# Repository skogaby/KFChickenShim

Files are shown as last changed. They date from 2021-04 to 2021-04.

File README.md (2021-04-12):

# KFChickenShim - Make your Sound Voltex 4 cabinet feel new again

So, you bought a Sound Voltex 4 cabinet, but weren't able to secure an official or clone upgrade kit for Sound Voltex V?

This is **KFChickenShim**, a simple PCB that adapts the various JST connectors found on a Sound Voltex IV IO board (known as **KFCA**) to standard connectors that allow you to easily connect the board to an off-the-shelf PC. Doing this, you can utilize a solution known as **KFChicken**, combined with **SpiceTools**, to run SDVX 5 or newer inside an older cabinet, complete with full IO, card reader, working lights, headphone support, etc. In addition, there is no perceivable latency or negative affect on gameplay, though your in-game offsets may not be what you're typically used to and might need adjustment for the new setup.

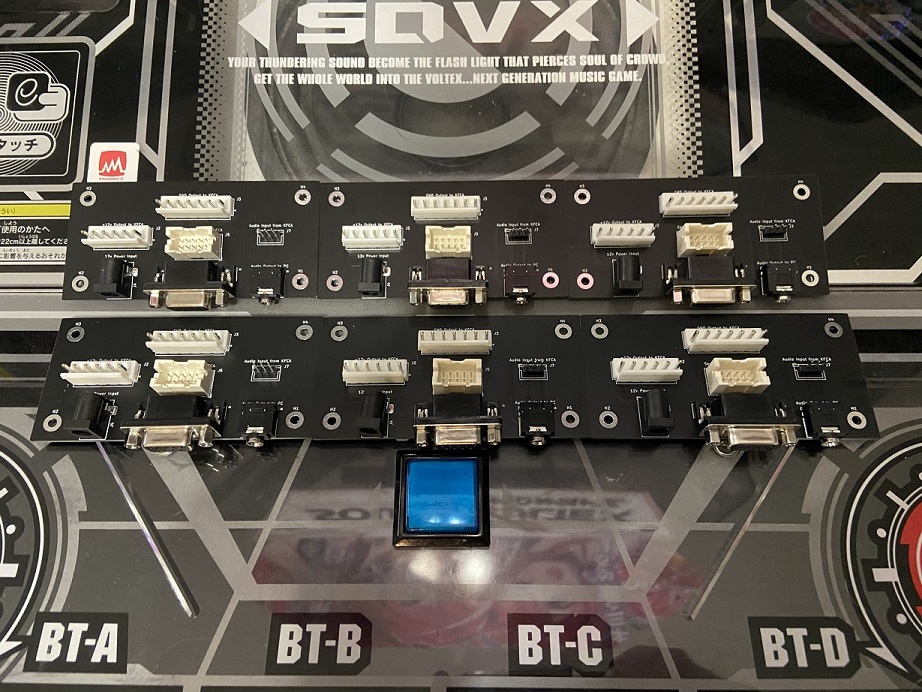
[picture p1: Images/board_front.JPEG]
PCB image 1

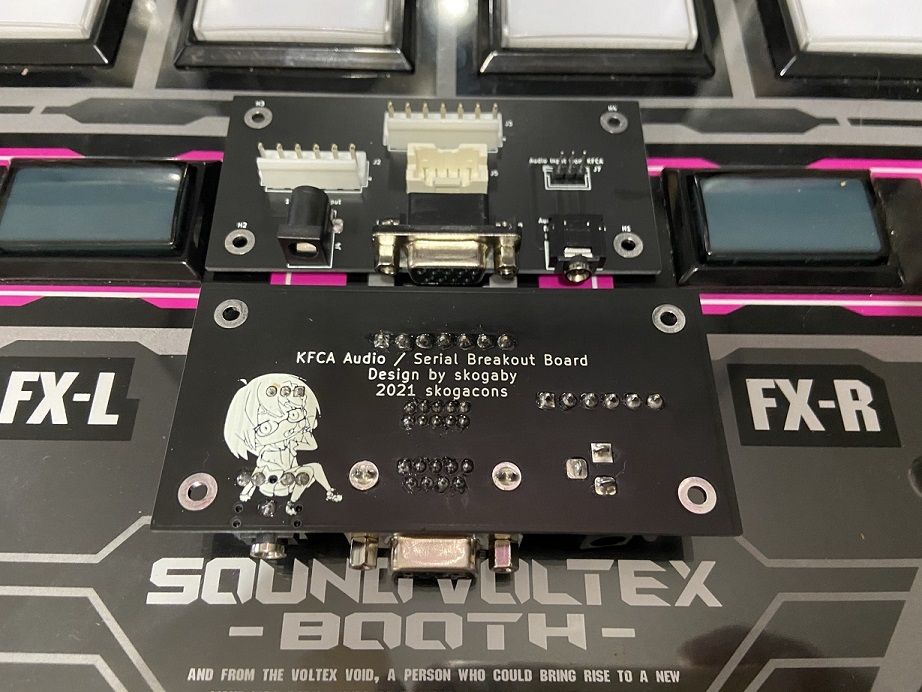
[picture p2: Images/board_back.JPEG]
PCB image 1


## Requirements

If you buy a pre-made PCB from me, you'll need the following:

* A KFChickenShim PCB (plus the components below)
  * DB9 serial cable. (**NOTE:** I've had better luck using DB9 serial -> USB cables, instead of using my motherboard's onboard serial port)
  * 3.5mm audio cable
  * 12v DC power adapter (5.5mm barrel jack connector)
* A newer PC that's powerful enough to run SDVX 5
* SpiceTools + KFChicken

Additionally, if you're ordering and assembling your own PCB, you'll need the following connectors:
* JST VH (6-pin and 7-pin)
* JST XAD (2x5-pin)
* 3x 2.5mm or 2.54mm pins (for the audio, I couldn't identify the exact JST connector Konami used for this but bare pins work fine)
* 5.5mm DC power barrel jack
* Sparkfun DB9 serial port (others might fit but the footprint was for this one, specifically)
  * https://www.sparkfun.com/products/429
* Sparkfun 3.5mm audio port (others might fit but the footprint was for this one, specifically)
  * https://www.sparkfun.com/products/8032

## Setup

Here are the instructions for setting up the board for use. I will not cover PCB assembly, all of the components are pretty self-explanatory in terms of placement on the board (they all have exactly one spot).

### Hardware Setup

#### Step 1: PC Removal

The first thing you'll want to do is remove the original BemaniPC from the cabinet. You'll need to disconnect every cable and remove the PC **entirely**, as the KFCA board is inside the PC case. In the below image, the board in the red rectangle is the one we're after.

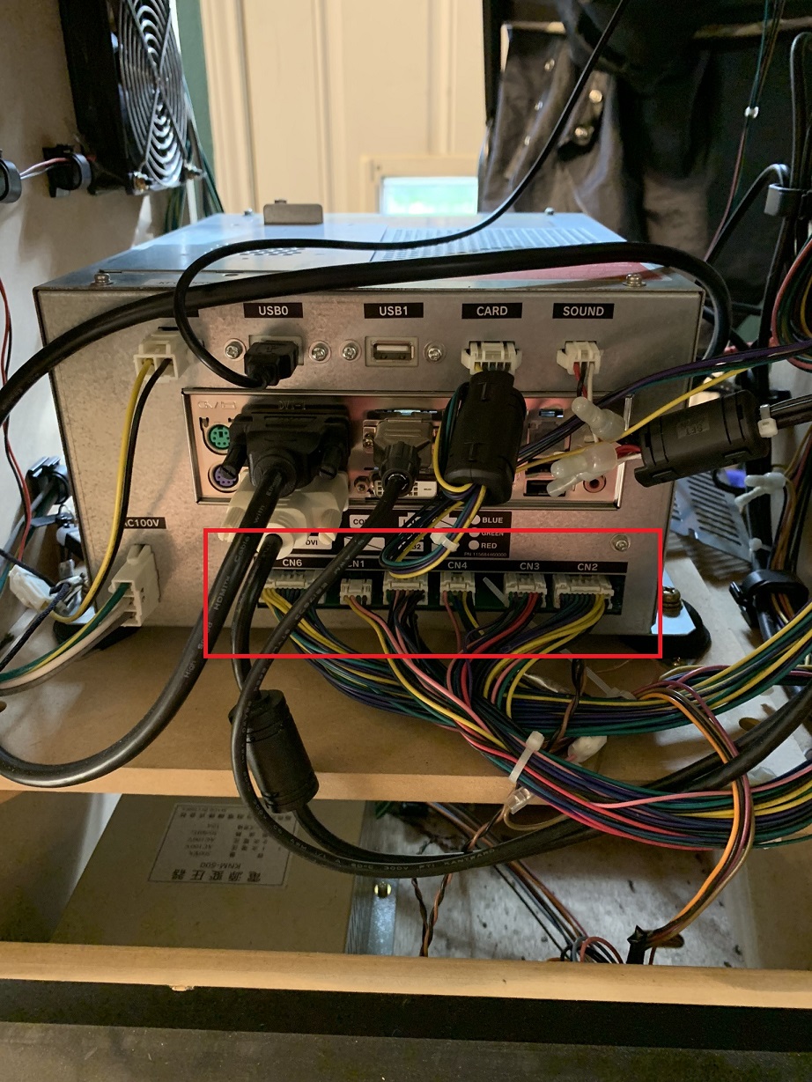
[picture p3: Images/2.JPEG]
BemaniPC


#### Step 2: Removing the KFCA board

Once the PC is removed from the cabinet, you'll need to remove the KFCA board from inside the PC case, which means you'll need to unscrew the case of the BemaniPC so you can get inside it. **NOTE**: If your cab is a gen 1 cabinet, your PC may look different from mine, but the process should be similar in terms of removing the IO.

Once the top is removed, you should see the exposed motherboard of the original PC. You'll more or less want to unplug all cables from the motherboard, to make it easy to remove since the KFCA sits underneath the motherboard. In the picture below, the connector in the red rectangle is the serial coming from the KFCA, and will be plugged into the KFChickenShim board.

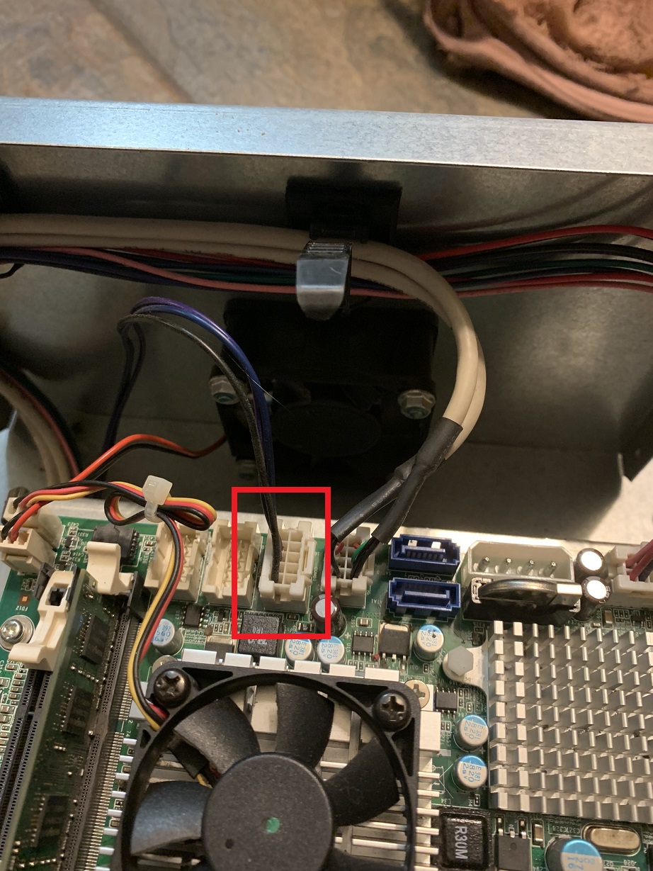
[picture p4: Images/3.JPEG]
Serial plug


Once the motherboard is removed entirely, you'll be greeted with a view similar to below.

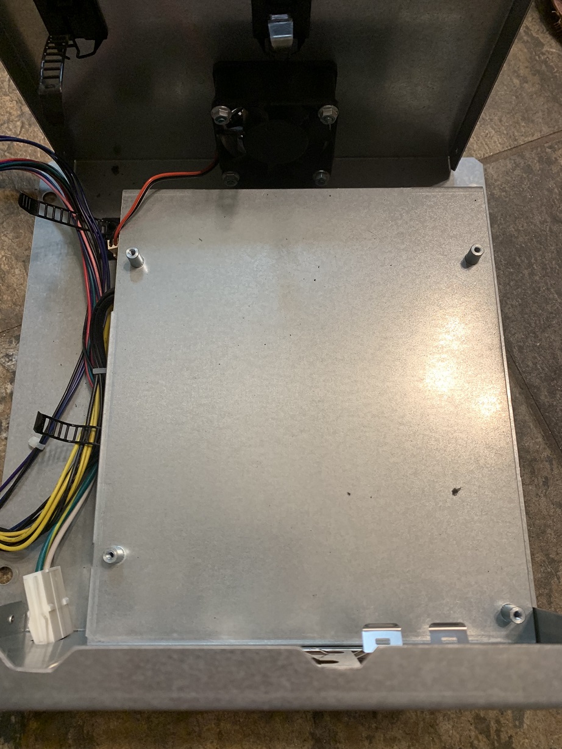
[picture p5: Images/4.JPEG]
Mobo mount


Go ahead and remove the metal plate that the motherboard was mounted to. Below it, you should see the KFCA board itself, as well as the power supply unit for the PC and the KFCA board.

***KFCA Board***

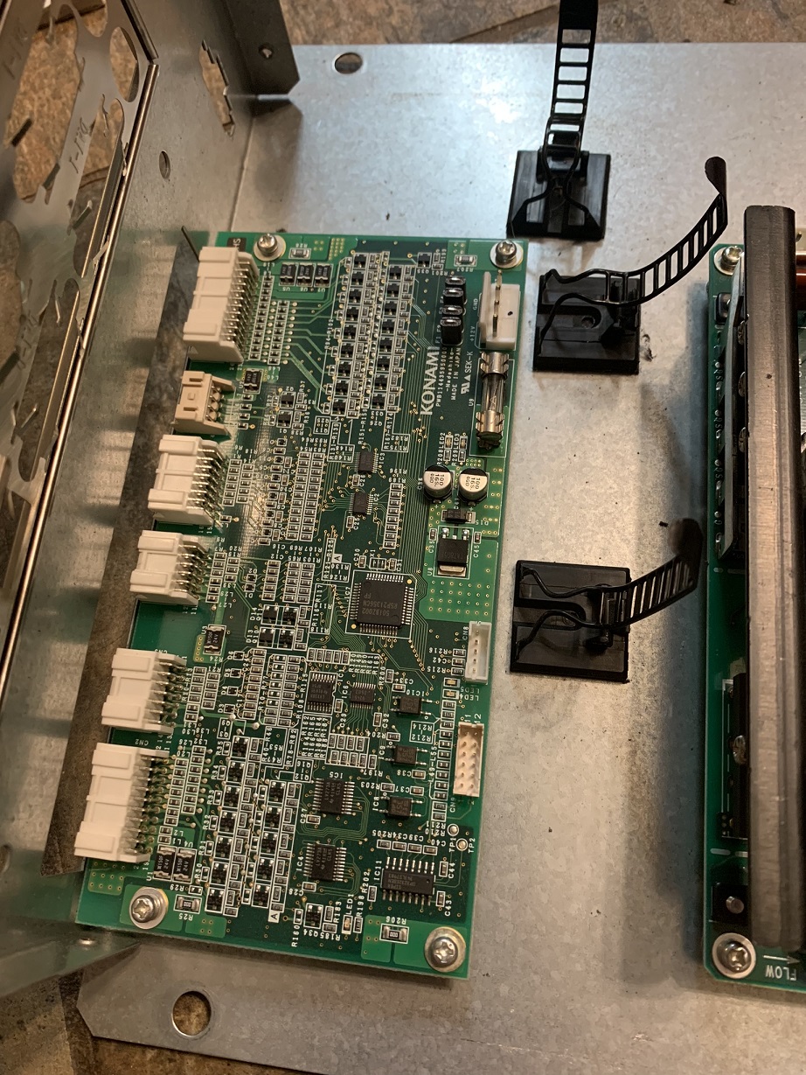
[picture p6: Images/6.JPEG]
KFCA Board


***Power supply, with power connectors for the KFCA board***

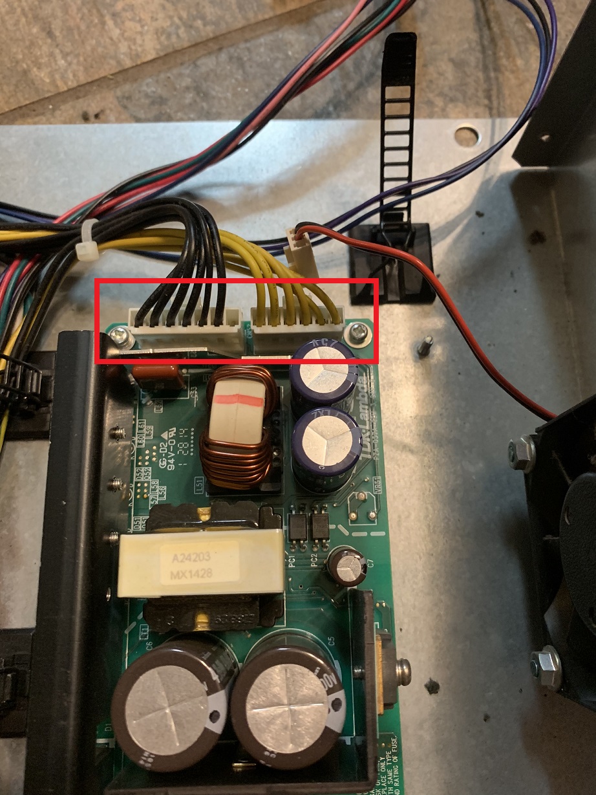
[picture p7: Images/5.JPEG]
BPC PSU


Once you unscrew the KFCA board, it should be free and ready for use.

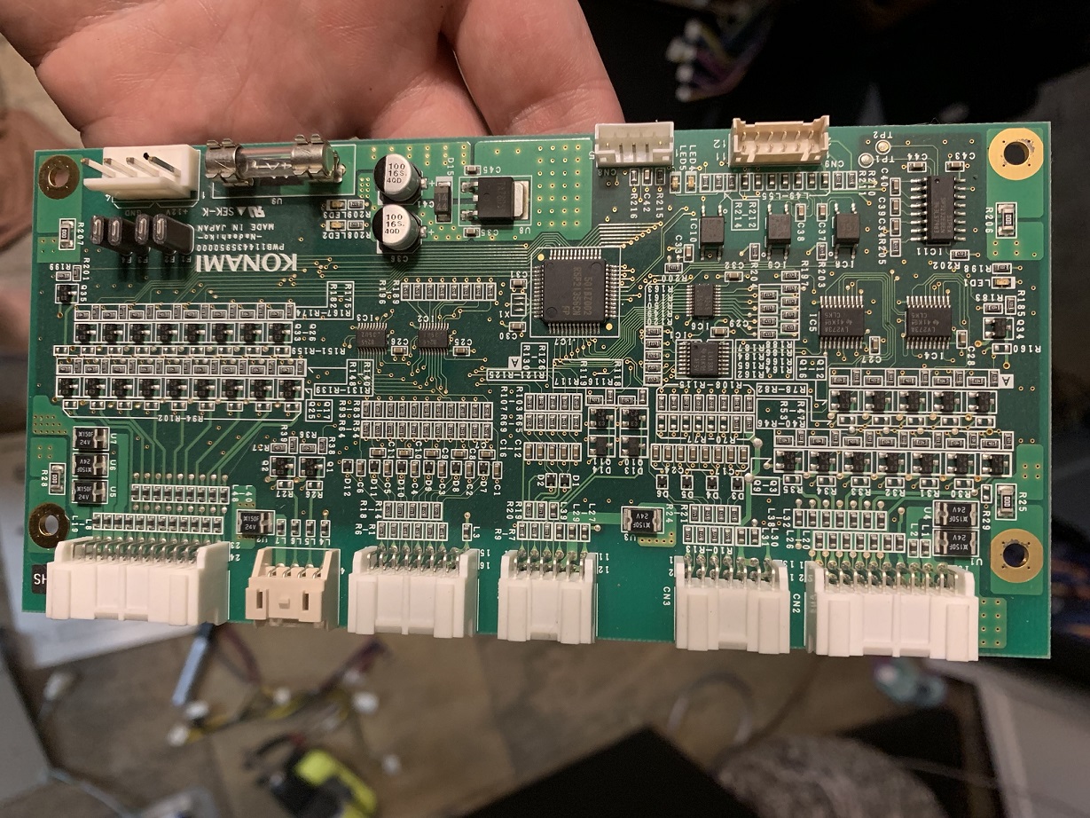
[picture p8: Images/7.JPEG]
Fresh KFCA


Below is the wiring harness that you should now have onhand for the KFCA board. Yours probably also has a plug that previously powered the PC, I just cut that off of mine since it's no longer being used. The wiring harness in the image is labeled appropriately, as we'll be referring to these later during assembly.

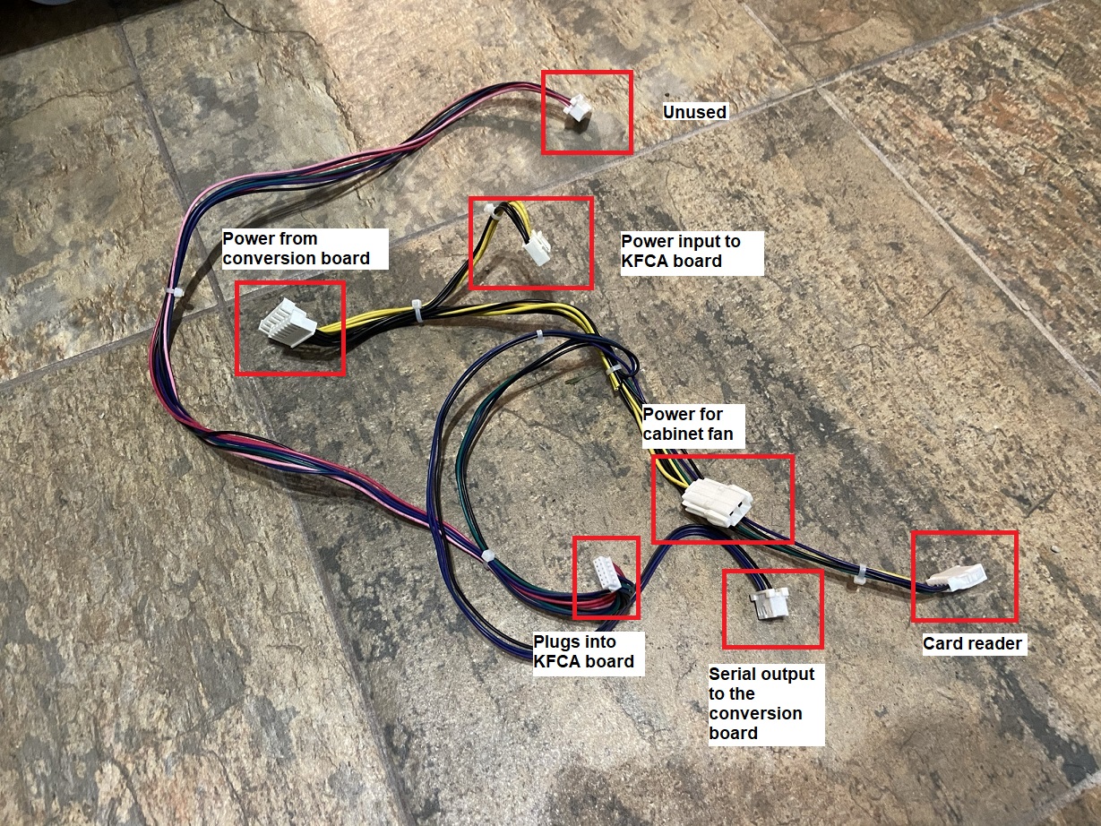
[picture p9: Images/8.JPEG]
Wiring Harness


#### Step 3: Installing the KFCA to the new PC

**NOTE:** I am *NOT* going to cover how to install the PC itself into your cabinet. This step can vary wildly depending on your setup. However, here is a picture of my personal cabinet, with a new PC installed and the IO removed. Please note that most cabinets have a 120v passthrough outlet sort of dangling at the end of a cord inside the cabinet. I highly recommend using this to power everything, but I had to pull that cable out of my cab for a different machine that needed one, so I spliced a regular wall outlet into the cab's power supply's 120v out. If you go this route, install an outlet cover box over the outlet (not pictured here).

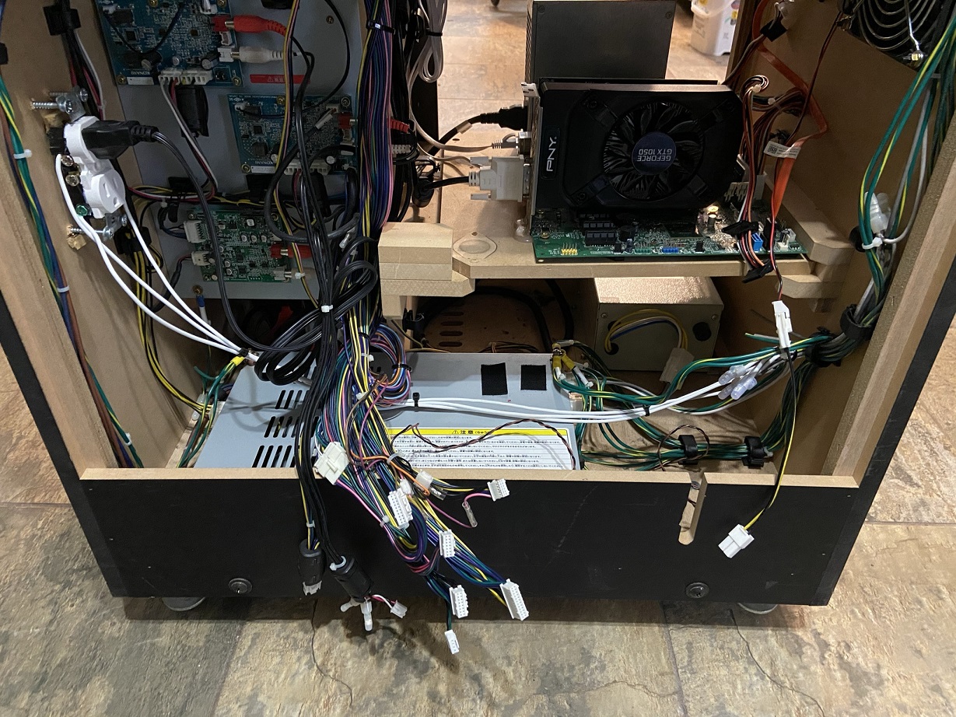
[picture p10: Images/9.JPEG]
Empty cab and PC


I'd also recommend making some sort of board like below with actual PCB/motherboard standoffs screwed into the wood. This will let you mount the PCBs inside the cab cleanly.

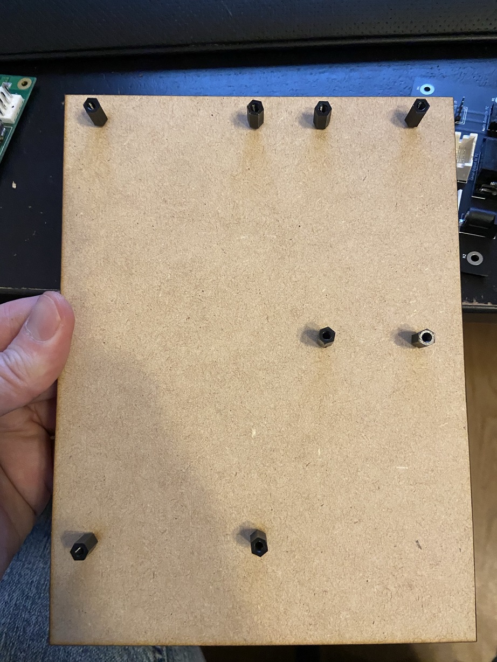
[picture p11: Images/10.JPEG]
Mounting panel

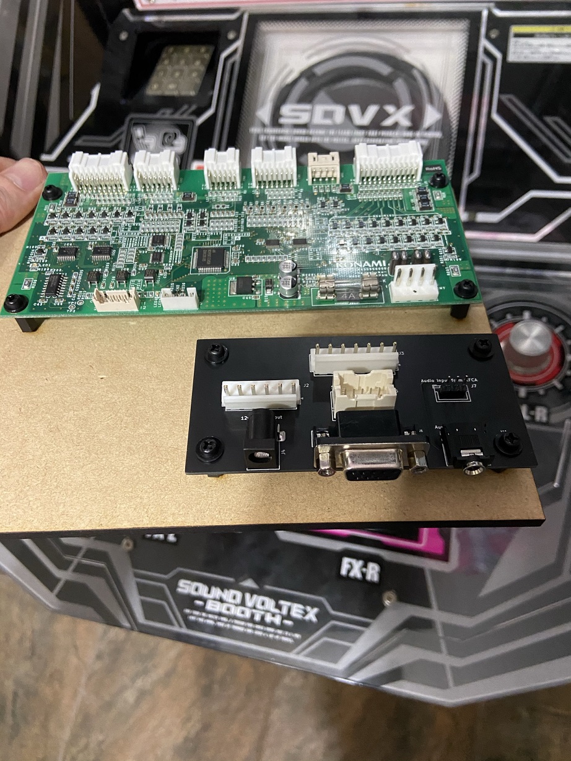
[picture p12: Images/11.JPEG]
Mounted PCBs


Go ahead and hook up the cables to the KFCA that are dangling inside the cabinet that previously connected to the front of the BemaniPC.

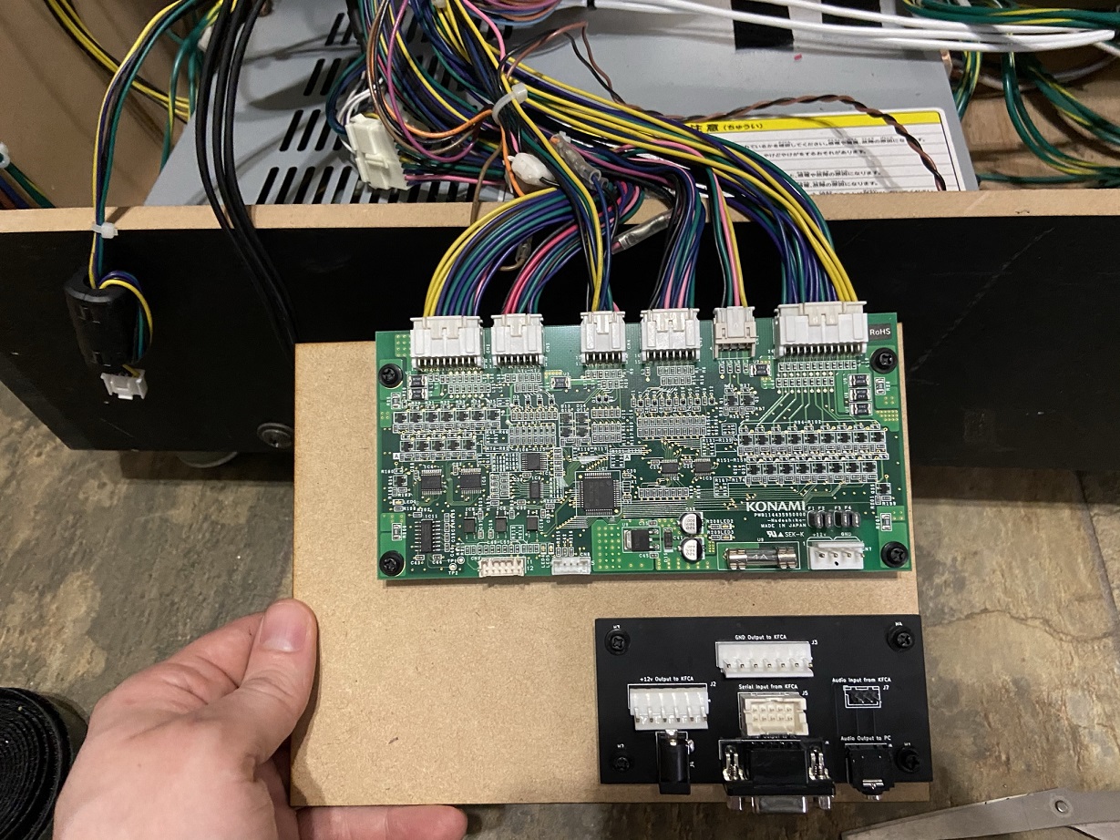
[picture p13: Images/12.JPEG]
First connections


Next, connect the power connections from the KFChickenShim board to the KFCA via the wiring harness pulled from the original cabinet. Yellow is 12v, black is ground.

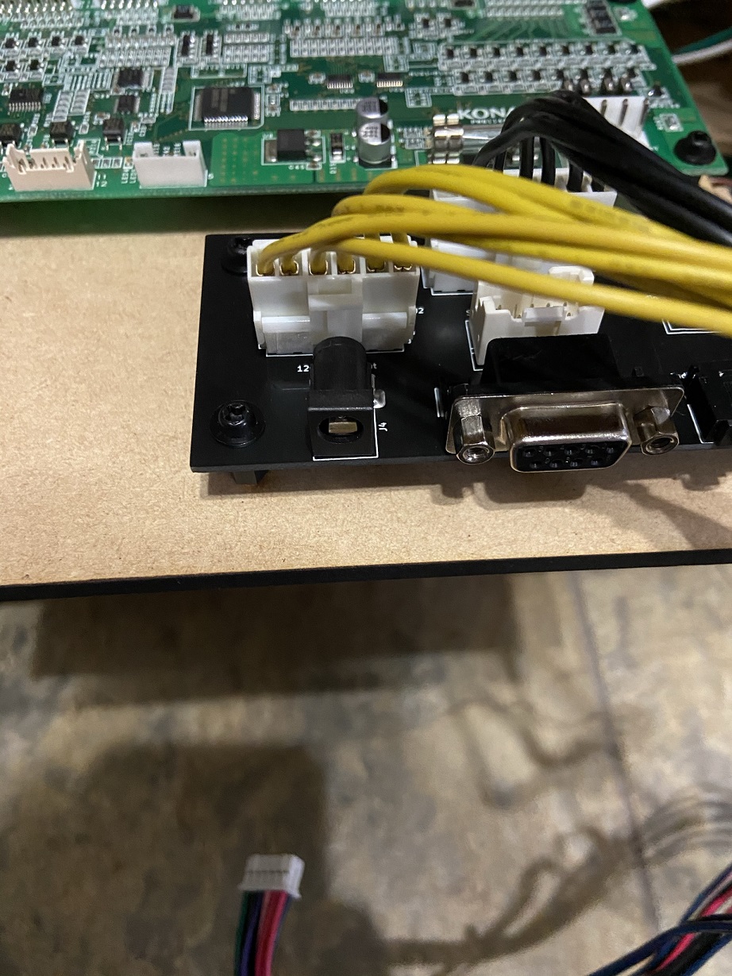
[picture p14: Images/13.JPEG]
Power

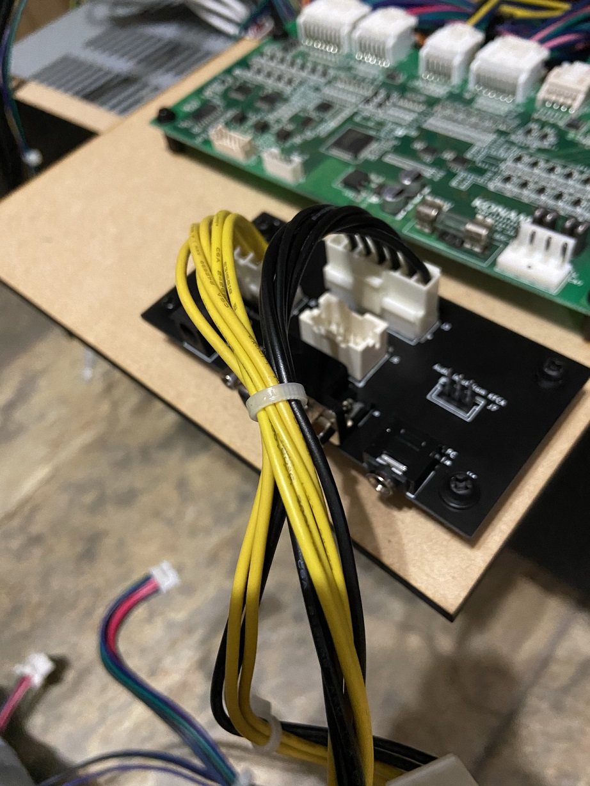
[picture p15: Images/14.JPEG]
Ground


Now connect the power cable to the KFCA board itself from the wiring harness.

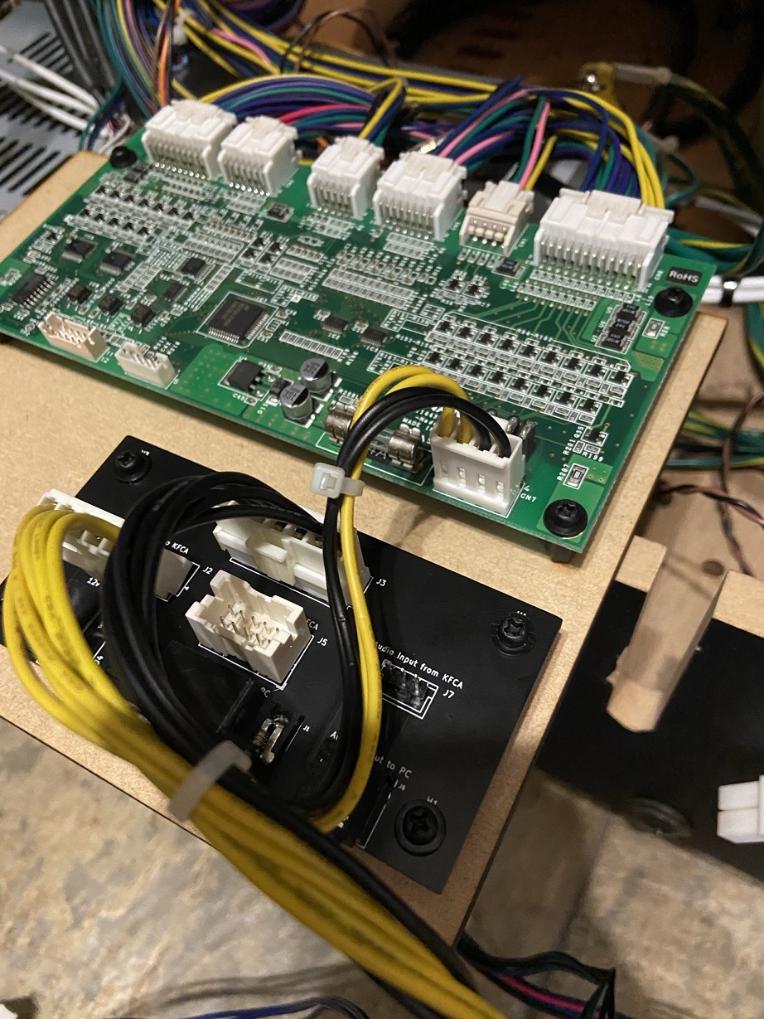
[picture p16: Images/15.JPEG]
KFCA power


Next, connect the wiring harness power for the cabinet fan that sits next to the PC.

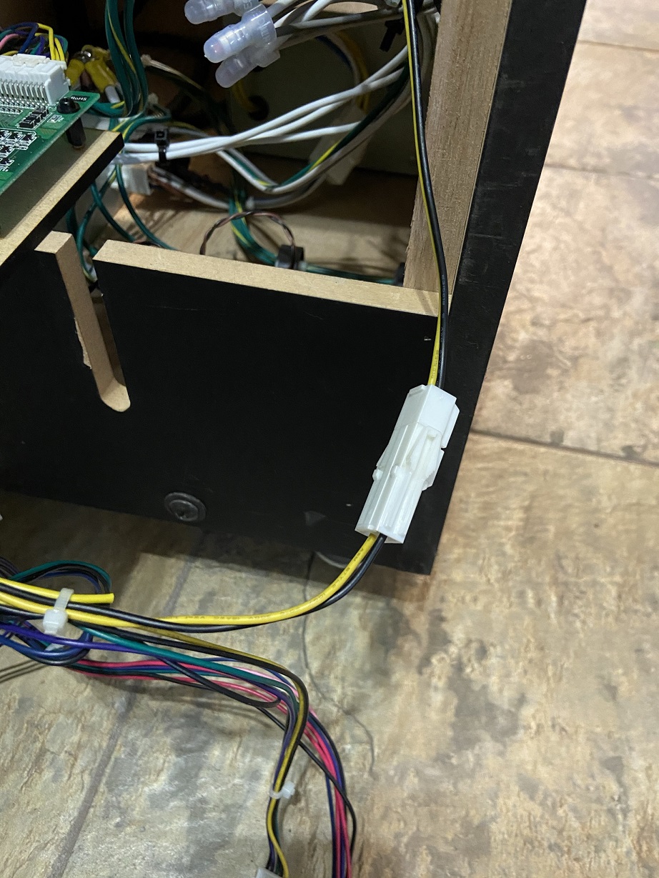
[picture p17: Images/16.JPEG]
Fan power


Connect the audio connector that's inside the cabinet (should be connected to 3 sets of red/white RCA cables on the other end) to the KFChickenShim board. Note the orientation of the plug, if it's plugged in backwards your left and right audio will be swapped.

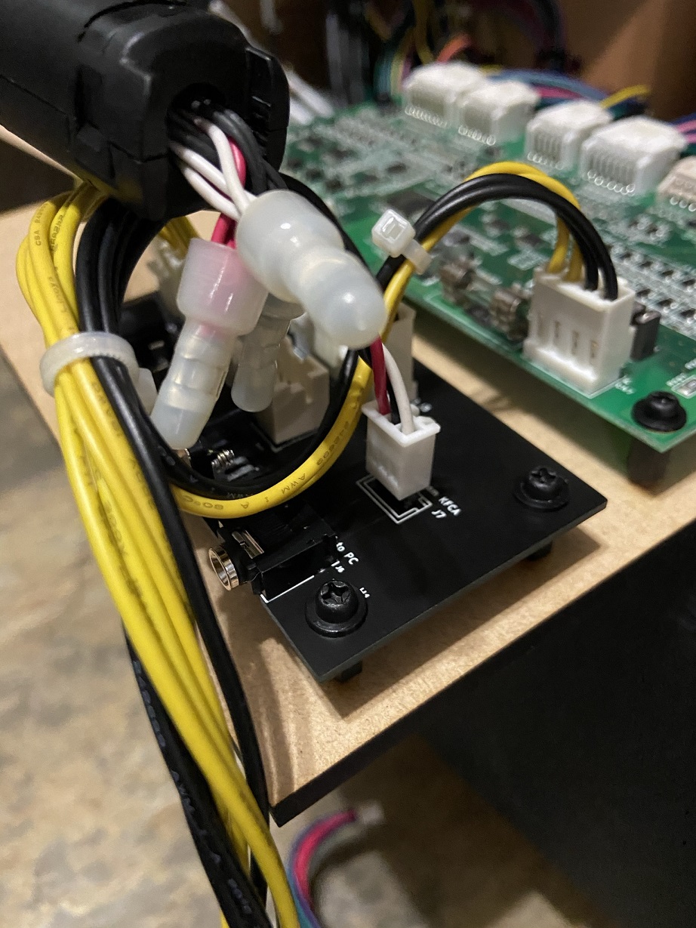
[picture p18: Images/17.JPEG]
Audio


Connect the card reader to the wiring harness from the KFCA.

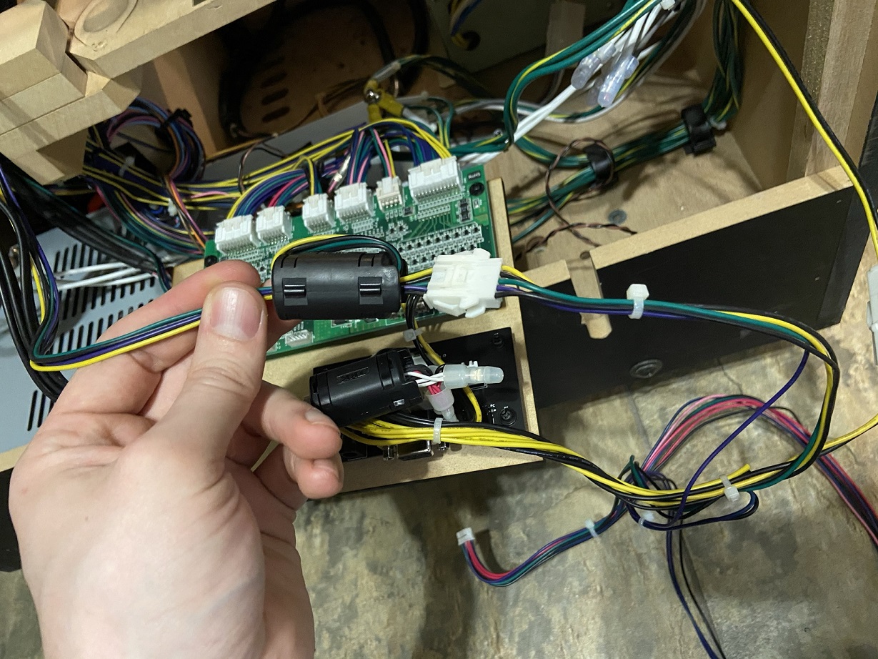
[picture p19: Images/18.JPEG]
Card reader


Connect the serial from the wiring harness to the KFChickenShim board.

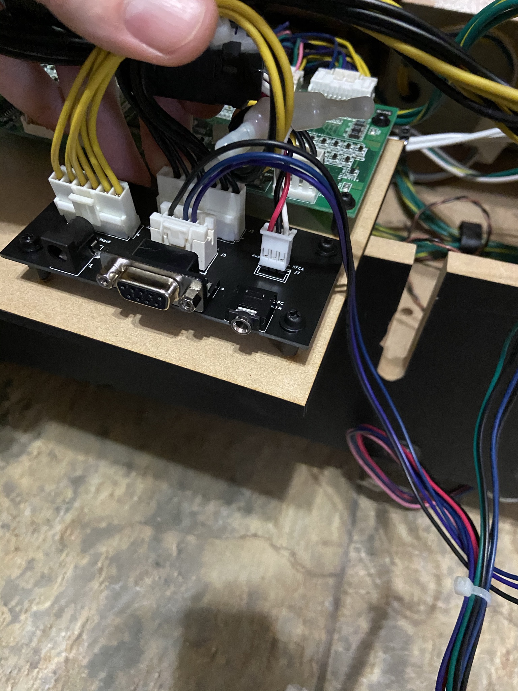
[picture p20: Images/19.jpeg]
Serial


Connect this plug from the wiring harness to the KFCA board.

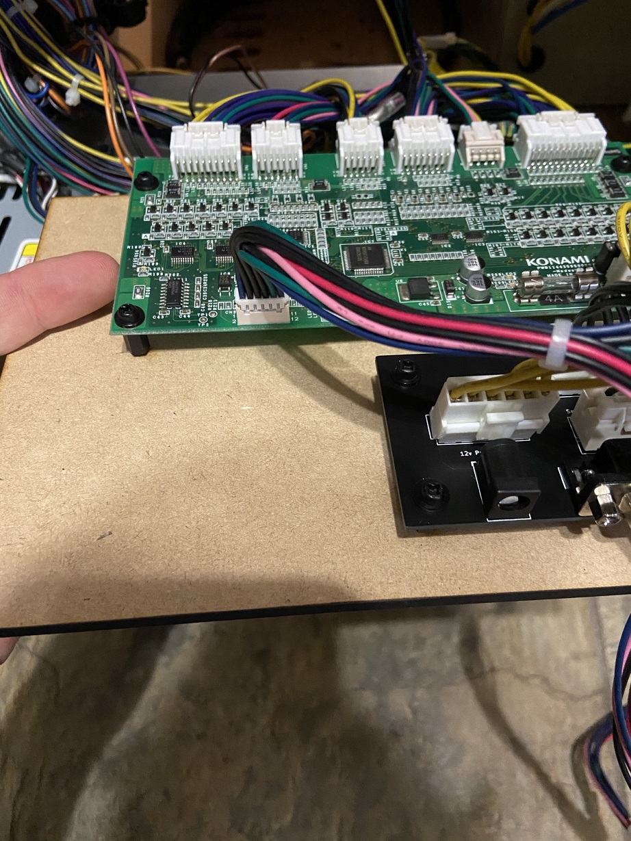
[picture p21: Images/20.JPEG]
Unidentified connector


Connect the power input, serial cable, and audio cables to the KFChickenShim board and connect it to the new PC.

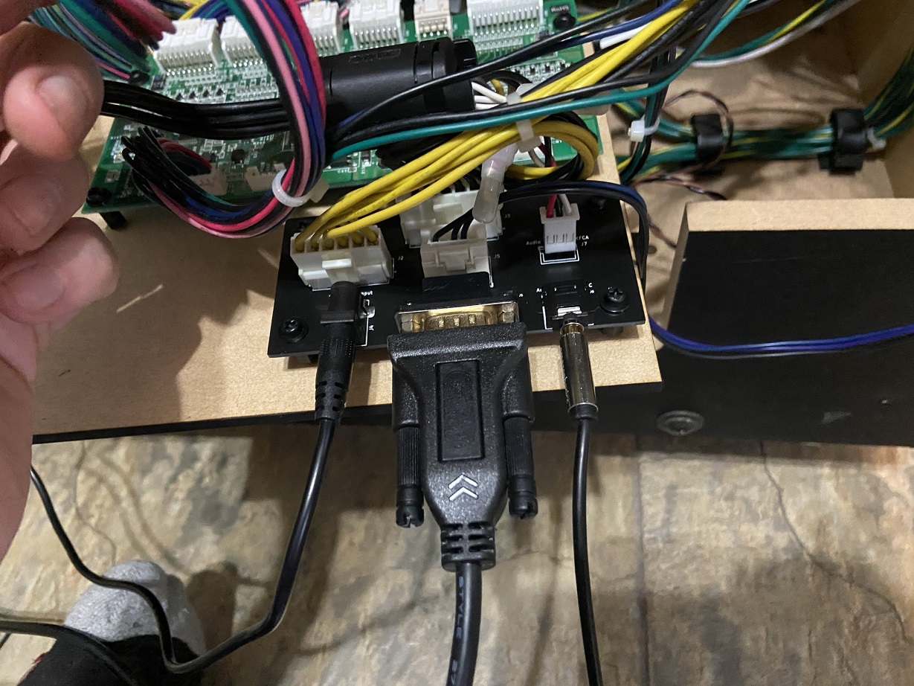
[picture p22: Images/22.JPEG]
More connections


Almost there! I'd recommend mounting the board like this to the inside of the cabinet rear panel. I used velcro strip to attach the board to the rear door, in case I need to remove the rear door entirely.

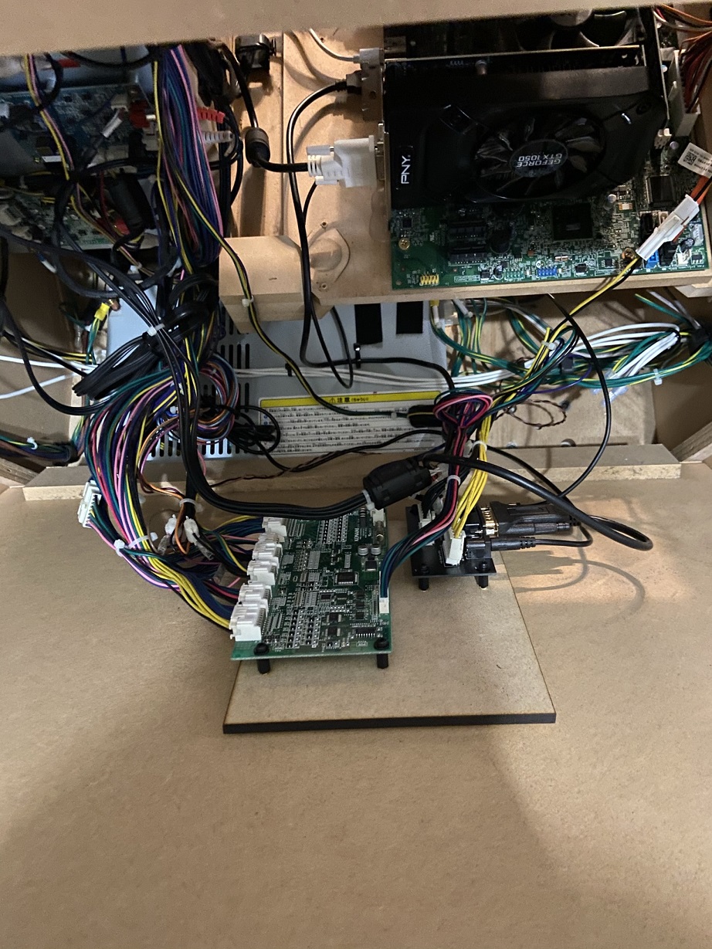
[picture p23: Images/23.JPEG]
Mounted board


If you power the cabinet on, you should see one red light on the KFCA, as well as one flashing light. 

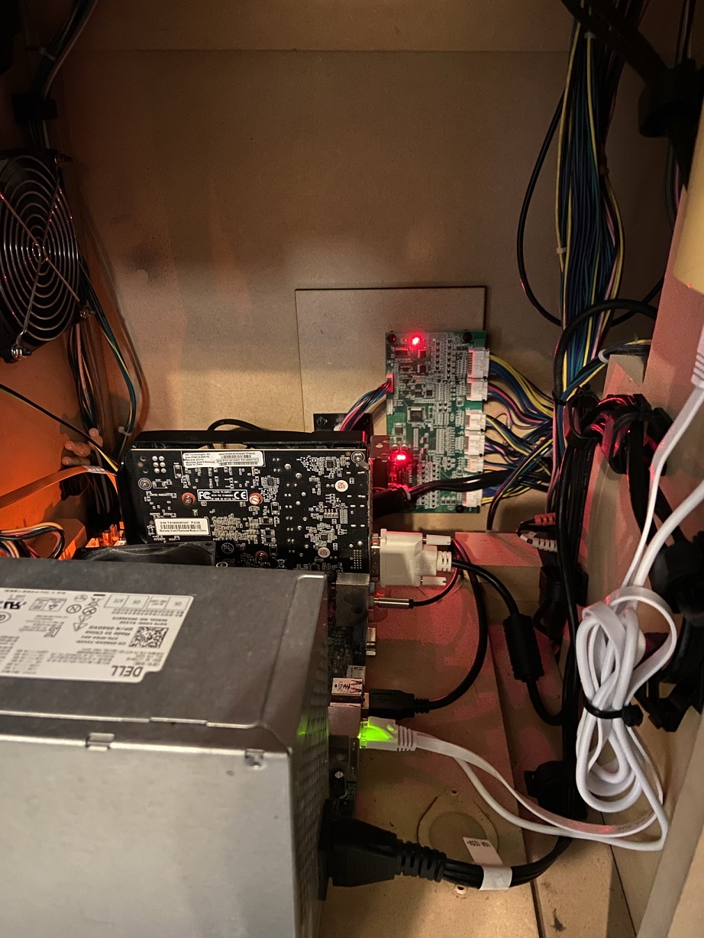
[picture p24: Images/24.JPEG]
Everything turned on


Hopefully this is the end of your hardware journey. Read the notes below for important tips when installing the software side of things.

#### Step 4: Setting up the software

Generally, just follow the KFChicken release thread's instructions for setting everything up, but here's a quick rundown and ***note the bolded item in particular:***
* Copy the `libacio.dll` file from your SDVX 4 installation and paste it into your SDVX 5 installation, renaming it to `libacio32.dll`.
* Copy `kfchicken32.dll` and `kfchicken32.exe` into your SDVX 5 installation. The KFChicken release thread says you can use the 64-bit version and the SDVX 5 DLLs but this doesn't work correctly as of this writing, so use the SDVX 4 modules and 32-bit KFChicken.
* Setup your `kfchicken.json` file as below, making sure to change the `com` field to the appropriate COM port to match whatever serial port the KFCA is hooked up to (can be found using Windows Device Manager, under `Ports (COM and LPT)`), and also the right settings to match your SpiceAPI port and password in `gamestart.bat` (covered next). **NOTE: The default `kfchicken.json` file has the `baudrate` field set to `57600`. I personally experienced unplayable knobs/analog inputs until I changed this value to `115200` instead.**
```json
{
  "acio_dll": "libacio32.dll",
  "com": 2,
  "baudrate": 115200,
  "host": "localhost",
  "port": 1337,
  "pass": "changeme",
  "boot_delay": 500,
  "poll_delay": 0,
  "soft_fail": false,
  "parse_cmd_line_args": true,
  "debug_hook": false,
  "watchdog_enable": false,
  "watchdog_time": 120000,
  "icca_enable": true,
  "icca_limit": 1500,
  "kfca_enable": true,
  "coin_enable": true,
  "coin_blocker_delay": 500,
  "volume_enable": true,
  "volume_sync": true,
  "volume_sound_default": 20,
  "volume_sound_limit": 0,
  "volume_woofer_default": 20,
  "volume_external_default": 100,
  "volume_headphone_default": 20,
  "lcdhandle_enable": true,
  "lcdhandle_port": "COM2",
  "lcdhandle_delay": 200
}
```
* Modify your `gamestart.bat` file to start KFChicken before starting Spice, and also to make Spice expose its API. Change the port and password to whatever you'd like, but make sure the `kfchicken.json` file has the same settings.
```bat
start ./kfchicken32.exe
start ./spice64.exe -api 1337 -apipass changeme -sdvx
```
* If all went well, you should finally be good to go, and SDVX 5 will be running using the old IO board!

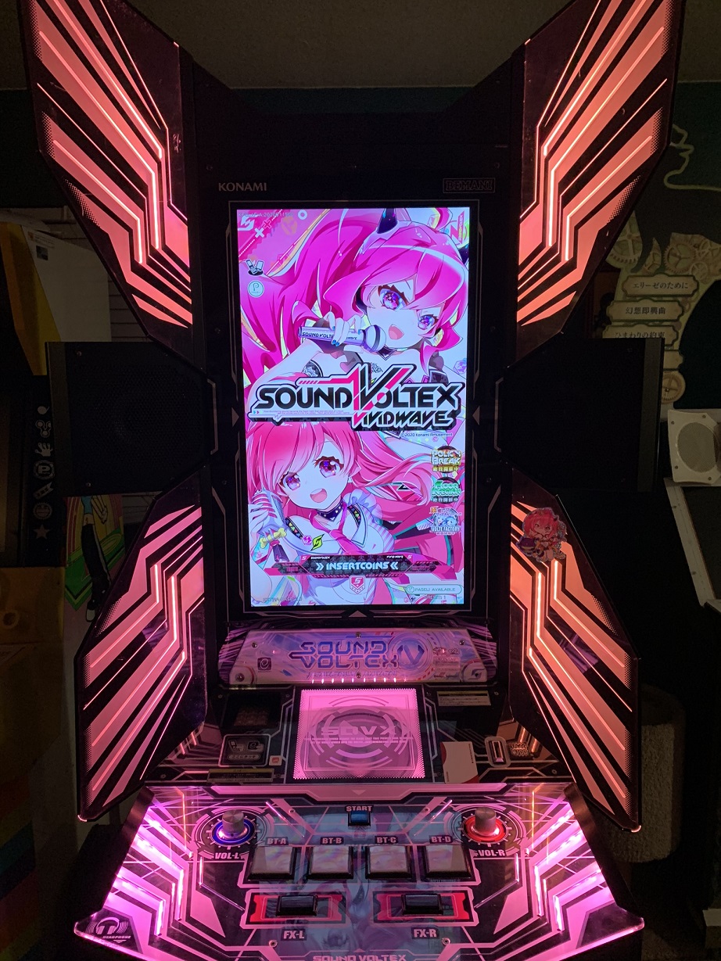
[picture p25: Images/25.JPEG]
Success


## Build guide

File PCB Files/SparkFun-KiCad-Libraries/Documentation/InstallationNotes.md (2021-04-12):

Installation Notes
----------------

* [The KiCad site](http://kicad-pcb.org/)

**KiCad installation**

* Uninstall previous versions of KiCad
* Download KiCad stable version 4.0.5 from [http://kicad-pcb.org/download/](http://kicad-pcb.org/download/windows/) and install
* After install, you'll be prompted to install "Wings 3D", check this box to be redirected to [http://www.wings3d.com/](http://www.wings3d.com/)
* Download and install the stable release 2.1.5

**Using the libraries**

* Create a local project (this is necessary because projects hold library path information)
* Open the "Schematic Library Editor"
* Prefrences -> Component Libraries
  * Remove all libraries from list
  * Add -> navigate to SparkFun-KiCad-Libraries -> select all .lib files -> open, then hit OK
  * Test by selecting an active library.  All sparkfun libraries should be displayed.  Close the library editor
* Open the "PCB Footprint Editor"
* Preferences -> Footprint Library Manager
  * Remove all (if any) libraries, hit OK
* Preferences -> Footprint Libraries Wizard
  * Next (files on my computer)
  * Navigate to SparkFun-KiCad-Libraries -> select all .mod files and hit ok
  * Next
  * Select for this project only
  * Next
  * Close the editor
* Save the project (Green arrow into extern HDD icon, no menu exists)

Now, this project is linked to the libraries.  Open a schematic and place components.  See KiCad enginursday post for converting from schematic into board (Note: You need to have nets for this to work... not just unconnected components)

**License Information**

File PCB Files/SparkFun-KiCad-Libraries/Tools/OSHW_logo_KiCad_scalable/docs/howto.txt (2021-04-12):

How to make your own:
---------------------

Watch / read this first:

* http://www.kicad-pcb.org/display/KICAD/Videos+by+zupnikal

The last two videos should be helpful for how to create a custom .emp file from images.

* http://www.re-innovation.co.uk/web12/index.php/en/blog-75/230-adding-logo-to-kicad

If you use linux (which you should), you don't have to use the online-scaler. Just use the scripts!

---

* Create a folder to hold your new footprint library.
* Copy the scripts 'make_lib.sh' and 'scale.pl' into that folder.
* Make sure these files are executable (chmod u+x ...).
* Copy your custom .emp file into that foler.

* Run the 'make_lib.sh' script as follows:

./make_lib.sh input-file.emp lib-name.mod START END

START and END are placeholders for positive integer numbers (1,2,3...) that determine
the range of created footprint sizes. The units are metric (mm).

The 'lib-name.mod' file will show up in the 'lib' sub-folder. Add it to your pcbnew
library settings as usual.

Footprints that are created for back-layers are automagically mirrored horizontally.
To place them onto a back-layer, hover the mouse-pointer over them and press 'f' for 'flip'.

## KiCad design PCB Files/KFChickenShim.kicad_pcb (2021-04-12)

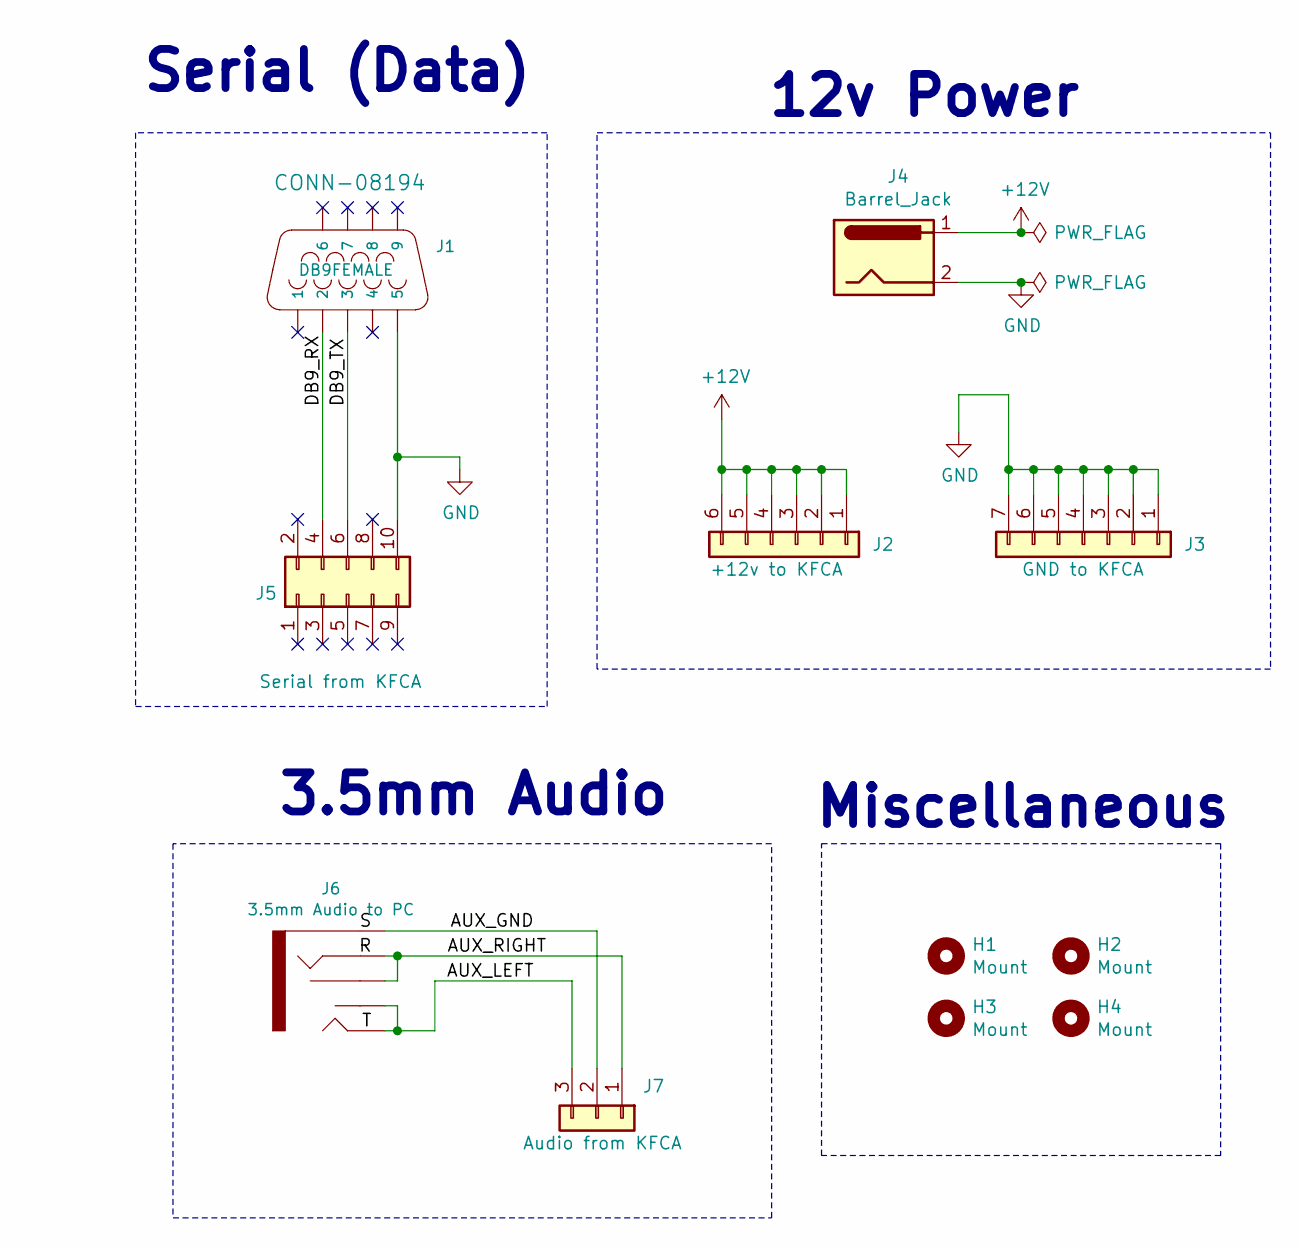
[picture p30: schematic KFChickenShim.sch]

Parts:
H1, H2, H3, H4: Mount; MountingHole_3.2mm_M3_Pad
J1: DB9FEMALE; DB9
J2: +12v to KFCA; JST_VH_B6P-VH_1x06_P3.96mm_Vertical
J3: GND to KFCA; JST_VH_B7P-VH_1x07_P3.96mm_Vertical
J4: Barrel_Jack; BarrelJack_Horizontal
J5: Serial from KFCA; JST_XAD_B10B-XADSS-N_2x05_P2.50mm_Vertical
J6: 3.5mm Audio to PC; AUDIO-JACK
J7: Audio from KFCA; JST_XH_B3B-XH-A_1x03_P2.50mm_Vertical

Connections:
+12V: J2.1, J2.2, J2.3, J2.4, J2.5, J2.6, J4.1
/AUX_GND: J6.SLEE (SLEEVE), J7.2
/AUX_LEFT: J6.TIP, J6.TSH, J7.3
/AUX_RIGHT: J6.RING, J6.RSH, J7.1
/DB9_RX: J1.2, J5.4
/DB9_TX: J1.3, J5.6
GND: J1.5, J3.1, J3.2, J3.3, J3.4, J3.5, J3.6, J3.7, J4.2, J5.10

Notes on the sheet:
Serial (Data)
12v Power
3.5mm Audio
Miscellaneous

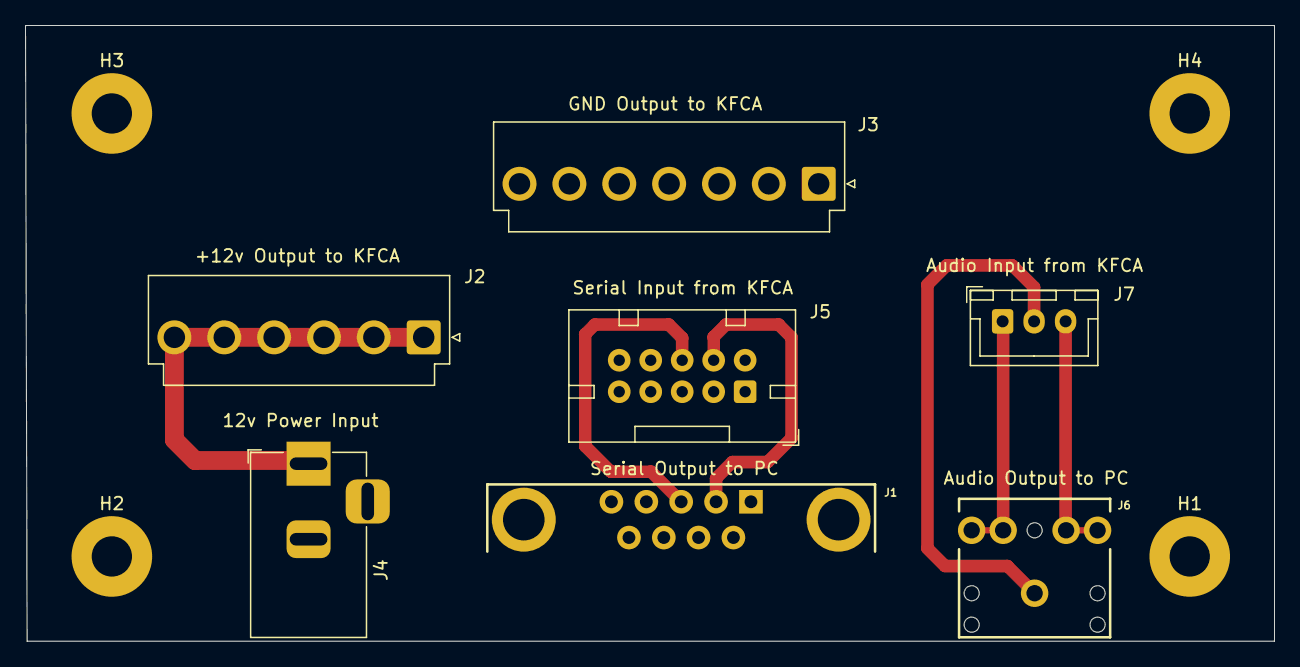
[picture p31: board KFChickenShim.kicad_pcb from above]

Board: 2 copper layers, 99.2 x 48.9 mm, 11 parts (0 on the bottom side), 7 nets.

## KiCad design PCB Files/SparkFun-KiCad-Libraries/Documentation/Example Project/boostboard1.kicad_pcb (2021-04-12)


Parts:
C1, C2, C3: 22UF-0805-6.3V-20%; 0805
D1: LED-RED0603; LED-0603
FD1, FD2: FIDUCIAL1X2; FIDUCIAL-1X2
H1: STAND-OFF
J1, J3: CONN_02; 1X02
J2: CONN_01; 1X01
JP1: JUMPER-SMT_2_NO; SMT-JUMPER_2_NO_SILK
L1: INDUCTOR-CDRH-4.7UH; INDUCTOR_2.2UH
LOGO1: SFE_LOGO_NAME_FLAME.1_INCH; SFE_LOGO_NAME_FLAME_.1
LOGO2: OSHW-LOGOS; OSHW-LOGO-S
R1: 10KOHM-0603-1_10W-1%; 0603
R2, R4: 100KOHM-0603-1_10W-1%; 0603
R3, R5: 820KOHM-0603-1_10W-1%; 0603
R6: 4.7KOHM-0603-1_10W-1%; 0603
U1: PAM2401; MSOP8

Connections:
/EN: J2.1, R1.2, U1.2 (EN)
/FB: JP1.2, R3.1, R4.2, U1.5 (FB)
/GND: C1.2, C2.2, C3.2, J1.1, J3.1, R2.2, R4.1, R6.1, U1.4 (AGND), U1.8 (PGND)
/LX: L1.P$2 (2), U1.1 (LX)
/RSET: R2.1, U1.6 (RSET)
/VBATT: C1.1, J1.2, L1.P$1 (1), R1.1, U1.3 (VIN)
/VCC: C2.1, C3.1, D1.A, J3.2, R3.2, R5.2, U1.7 (OUT)
unnamed: D1.C, R6.2
unnamed: JP1.1, R5.1

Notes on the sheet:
1A Booster
Jumper: Open for 5.0V operation Closed for 3.3V operation
Input
Output
Input Range: 0.9 to 4.75V For full output capacity, upwards of 3A may be required. For max operation, calculate with P=IV, using 6 watts. At 3.7V, Iin = 1.62A



Board: 2 copper layers, 15.2 x 15.2 mm, 21 parts (3 on the bottom side), 9 nets.

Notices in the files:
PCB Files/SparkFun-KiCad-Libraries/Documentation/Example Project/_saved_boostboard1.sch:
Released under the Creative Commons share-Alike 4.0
